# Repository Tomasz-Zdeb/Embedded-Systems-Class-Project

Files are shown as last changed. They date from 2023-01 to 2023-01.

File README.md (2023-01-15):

# Projekt zaliczeniowy

W ramach zaliczenia przedmiotu jesteśmy zobowiązani grupowo wykonać wspólny projekt, którego celem jest zaprojektowanie urządzenia elektronicznego opartego o mikroprocesor z rodziny **STM32**, służącego do rejestracji temperatury.

## Specyfikacja

* wykonanie projektu polega na zaprojektowaniu urządrzenia
* każdy komponent logiczny urządzenia powinien zostać dokładnie udokumentowany
* urządzenie powinno składać się z rzeczywistych komponentów elektronicznych dostępnych na rynku.
* wszelkie użyte komponenty elektroniczne powinny wnosić szacowaną wartość do kosztorysu
* projekt powinien zawierać schemat elektryczny całego urządzenia
* projekt ma formę dokumentu `.pdf`

## Cykl życia projektu

1. Ustalenie funkcjonalności, które urządzenie będzie realizować, na przykład:

* > pomiar temperatury za pomocą urządzenia pomiarowego np. **termorezystora**
* > przechowywanie szeregu czasowego wartości temperatur w pamięci trwałej
* > zapewnienie interfejsu do komunikacji z innymi urządzeniami, np. **Ethernet**
* > monitoring wartości temperatury w czasie rzeczywistym przy pomocy wyświetlacza alfanumerycznego **LCD**
  
2. Ustalenie jakie komponenty będą realizować zaplanowane funkcjonalności

* Należy mieć na uwadze ograniczenia interfejsów **I/O** mikrokontrolerów z rodziny **STM32** pod względem ilościowym i jakościowym . Do przeglądu dostępnych mikroprocesorów zaleca się użycie oprogramowania z [SDK](https://www.st.com/en/development-tools/stm32-software-development-tools.html#products) firmy **ST** używanego w ramach przedmiotu **Mikroprocesory i Mikrokontrolery**.

3. Opracowanie każdej z funkcjonalości w kontekście użytego komponentu

* opis charakterystyki komponentu i jego zastosowania w urządzeniu
* określelnie uproszczonego schematu podłączenia komponentu z danym interfejsem mikroprocesora
* uwzględnienie użytych komponentów w kosztorysie

4. Opracowanie całościowego schematu elektrycznego urządzenia

5. Opracowanie dokumentu stanowiącego podstawę do eksportu do `.pdf` / eksport bezpośredni `.md` => `.pdf`

* zawiera krótki opis urządzenia na wstępie
* (opcjonalnie) zawiera schemat logiczny urządzenia
* zawiera schemat elektryczny urządzenia
* zawiera opis każdej z funkcjonalności urządzenia w kontekście użytego komponentu
* zawiera kosztorys urządzenia
* zawiera uczestników projektu

6. Eksport dokumentu do `.pdf` i prezentacja prowadzącemu przedmiot: <mateusz.michalek@pk.edu.pl>

## Realizacja projektu

* Zaleca się korzystanie z edytora: [VS Code](https://code.visualstudio.com/)

  * sugestia dotycząca zalecanego rozszerzenia zawierającego pomoc w pisaniu dokumentów `.markdown` powinna pojawić się automatycznie. W przeciwnym wypadku ID: `DavidAnson.vscode-markdownlint`

* Treść projektu znajduje się w pliku [main](./main.md). Pracując nad projektem należy umieszczać tam owoce swojej pracy korzystając z formatowania języka [markdown](https://www.markdownguide.org/basic-syntax/).

* Obrazy znajdują się w katalogu `./images/`. Dodawanie obrazu do dokumentu polega na umieszczeniu obrazu w katalogu, a następnie stworzeniu odwołania w dokumencie [main](./main.md), np. `(alternatywny_tekst_dla_obrazu)[./images/]`

* Każdą jednostkową część pracy [commitujemy](https://git-scm.com/docs/git-commit) w lokalnym repozytorium na swojej maszynie na branchu dedykowanym danemu **issue**.

* W celu uaktualnienia centralnego repozytroium, należy wypushować brancha do centralnego repozytorium i otworzyć [pull request](https://docs.github.com/en/desktop/contributing-and-collaborating-using-github-desktop/working-with-your-remote-repository-on-github-or-github-enterprise/creating-an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) danego brancha z branchem **master**

* Za pomocą funkcjonalości serwisu **GitHub** - [Issues](https://github.com/features/issues):

  * przypisujemy dane zadanie do swojej osoby
  * tworzymy nowe zadania

## Status projektu

- [x] Inicjalizacja repozytorium
- [x] Stworzenie struktury projektu
- [x] Stworzenie zasad współtworzenia projektu
- [x] Dodanie wszystkich uczestników jako współtwórców repozytorium na **GitHub-ie**
- [x] **Issue**: Ustalenie funkcjonalności projektu
- [x] Utworzenie **issues** odpowiadających wszystkim funkcjonalnościom
- [x] Utworzenie **issues** odpowiadających pozostałym elementom realizacji projektu jak: **stworzenie schematu elektrycznego**
- [X] Realizacja rzeczonych issues
- [X] Uzupełnienie składu grupy
- [X] Publikacja projektu w formacie `.pdf`
- [X] Dostarczenie projektu do prowadzącego laboratorium (projekt zaliczony na ocenę: 5)

## Schemat elektryczny

Na podstawie researchu przeprowadzonego w [Issue: #4](https://github.com/Tomasz-Zdeb/Embedded-Systems-Class-Project/issues/4) schemat elektryczny urządzenia będzie tworzony przy pomocy oprogramowania: [KiCad](https://www.kicad.org/).

Schemat elektyczny znajduje się w katalogu: `/schematics/`

## Zadania których nie udało się zrealizować

- opis menu wraz z obsługą przy pomocy przycisków
- graficzny projekt gotowego urządzenia wraz z obudową
- opis modułu rozszerzeń
- przygotwanie kilku wariantów wyposażenia (wraz z cennikiem)

## Materiały

<p align="center">

zdjecie tablicu z sugestiami prowadzącego

</p>

## Opiekun repozytorium

### [Tomasz Zdeb](https://github.com/Tomasz-Zdeb)

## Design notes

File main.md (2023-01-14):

# Systemy Wbudowane - Projekt Grupy Laboratoryjnej 04

Realizacja projektu polega na zaprojektowaniu urządzenia embedded (systemu wbudowanego) do pomiaru temperatury. Projekt urządzenia w teorii mógłby stanowić podstawę do konstrukcji fizycznego prototypu urządzenia. Zakres projektu obejmuje dobór komponentów, mając na uwadzę:

- kompatybilność
- cenę
- rozmiary
- dostępność
- przystępność komponentu (tj. dostępność dokumentacji i schematów pozwalających na integrację komponentu)

W projekcie przedstawiono także schemat elektryczny potencjalnego urządzenia obrazujący połączenia komponentów przy zastosowaniu odpowiednich interfejsów.

## Skład grupy

- Imię Nazwisko (ta sekcja zostanie uzupełniona przed wysyłką projektu aby nie przechowywać danych uczestników w publicznym repozytorium)

## Specyfikacja urządzenia

Projektowane urządzenie stanowi kompaktowe i przystępne cenowo rozwiązanie do monitorowania temperatory przy pomocy termopary, z odczytem w czasie rzeczywistym lokalnie i zdalnie oraz zapisem na zewnętrznym nośniku. Urządzenie oparte jest o mikroprocesor: [STM32L151QDH6](https://www.mouser.pl/ProductDetail/STMicroelectronics/STM32L151QDH6?qs=pmcUWs1B1IIEPym5rr0MIA%3D%3D)

## Funkcjonalności

- Pomiar temperatury (przy pomocy termopary)
- Wyświetlanie warotści temperatury na alfanumerycznym wyświetlaczu **LCD** w czasie rzeczywistym
- Zapis pomiarów na karcie **micro SD**
- Możliwość odczytu aktualnej wartości i wartości zapisanych przez łączność **Bluetooth**
- Ustawienie alarmu, tj. wartości temperatury której przekroczenie (poniżej lub powyżej - w zależności od wybranego trybu) powoduje emisje sygnału dźwiękowego oraz powiadomienia w przypadku łączności **Bluetooth**

### Pomiar temperatury

W urządzeniu do pomiaru temperatury wykorzystywane są termopary typu K. Do interpretowania oraz przekształcania wyników pomiaru termopar wykorzystywane są dodatkowo konwertery **MAX31855KASA**.

#### Termopara

Poniżej przedstawiona jest częściowa charakterystyka wykorzystywanej termopary tpu K:

<p align="center">

| Zakres temperatur  | Precyzja pomiaru | Zakres napięcia wyjściowego |
| :---: | :---: | :---: |
| od -100°C do 500°C | ±2°C | od -6mV do +20mV |

</p>

#### Konwerter

Poniżej przedstawiona jest częściowa charakterystyka wykorzystywanego konwertera **MAX31855KASA**:

<p align="center">

| Zakres temperatury pracy | Rozdzielczość mierzonej temperatury |
| :---: | :---: |
| od -40°C do 125°C | 0.25°C |

</p>

Precyzja pomiaru a mierzona temperatura:

<p align="center">

| Mierzona temperatura | Temperatura pracy  | Precyzja pomiaru |
| :---: | :---: | :---: |
| od -200°C do +700°C  | od -20°C do +85°C  | ±2°C |
| od +700°C do +1350°C | od -20°C do +85°C  | ±4°C |
| od -270°C do +1372°C | od -40°C do +125°C | ±6°C |

</p>

#### Funkcjonalność

Pomiar temperatury odbywa się za pomocą termopar typu K. Typ K został wybrany z uwagi na dużą uniwersalność, niszki koszt i powszechność. Dodatkowo typ K oferuje odpowiednio szeroki zakres temperatury pomiaru. By ułatwić interpretacje wyników pomiaru termopary, wykorzystywane są konwertery **MAX31855KASA**, które przekształcają napięcie wyjściowe termopar na wartość temperatury w trywialnym do odczytania sygnale cyfrowym, niewymagającym dodatkowych przekształceń lub obliczeń. Sygnał cyfrowy z konwerterów jest następnie przesyłany przez SPI do mostka SC18IS606, z którego do mikrokontrolera przesyłany jest po I²C.

#### Schemat podłączenia konwertera i termopary

<p align="center">
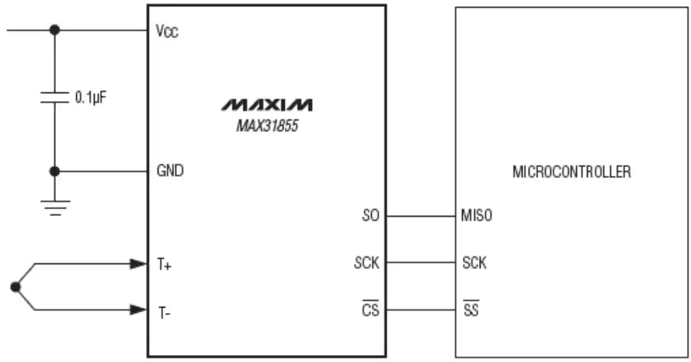
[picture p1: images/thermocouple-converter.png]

</p>

### Monitoring pomiaru w czasie rzeczywistym na alfanumerycznym ekranie LCD

#### Funkcjonalność

W urządzeniu do wyświetlania aktualnych wyników pomiarów wybraliśmy [LCD 2x16 wraz z konwerterem I²C LCM1602](https://botland.com.pl/wyswietlacze-alfanumeryczne-i-graficzne/2351-wyswietlacz-lcd-2x16-znakow-niebieski-konwerter-i2c-lcm1602-5904422309244.html). Możemy sterować zarówno wyświetlanym tekstem jak i podświetleniem, włączając lub wyłączając je w dowolnej chwili.  

#### Interfejs

Mikrokontroler, jako master w magistrali I2C, wysyła komendy i dane do konwertera I²C, który przetwarza je i przesyła do wyświetlacza LCD. To pozwala na komunikację między mikrokontrolerem, a wyświetlaczem za pomocą tylko dwóch linii SDA i SCL, zamiast wielu linii zwykłego interfejsu.

#### Schemat podłączenia konwertera i wyświetlacza

<p align="center">
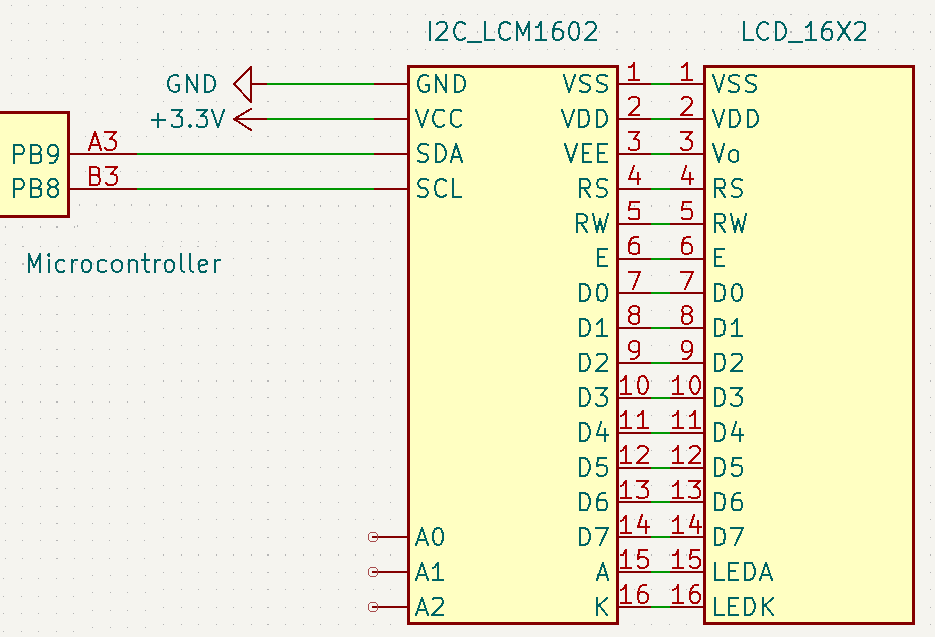
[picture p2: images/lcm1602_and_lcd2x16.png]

</p>

Warto też zauważyć, że w naszym konwerterze znajdują się niewykorzystane zworki do zmiany adresu. Z racji, iż mamy tylko jedno urządzenie nie musimy zmieniać owego adresu.

### Zapisywanie szeregu czasowego pomiarów na karcie Micro SD

Mikroprocesor **STM32L151QDH6** obsługuje funkcjonalność **SDIO** czyli natywną obsługę kart **SD** i **micro SD**.

#### Karta

Urządzenie korzysta z [karty SD](https://www.mouser.pl/ProductDetail/SanDisk/SDSDAF3-008G-I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) umieszczonej wewnątrz [gniazda](https://www.mouser.pl/ProductDetail/Amphenol-Commercial-Products/GSD090012SEU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). Karta z serii **Industrial** cechuje się dobrymi parametrami przesyłu jak i parametrami związanymi z wytrzymałością na warunki pracy (według [dokumentacji](https://www.mouser.pl/datasheet/2/669/SanDisk_02052018_SDSDAF3_SDSDQAF3-1285144.pdf)).

<p align="center">

| Wielkość pamięci | Maksymalna prędkość odczytu - zapisu | Zakres napięcia wejściowego |
| :---: | :---: | :---: |
| 8 GB | 80 MB/s - 50 MB/s | 2.7 V - 3.6 V |

</p>

#### Funkcjonalność

Urządzenie wykorzystuje czterobitowy tryb przesyłu (alternatywą był tryb jednobitowy), co wymagało zastosowania trzech dodatkowych linii danych, ale pozwala na osiągnięcie większej przepustowości komunikacji, co w związku z możliwością rozszerzenia urządzenia o dodatkowy moduł zwiększający maksymalną ilość podłączonych termopar jest uzasadnione.

Zgodnie z [artykułem](https://controllerstech.com/interface-sd-card-with-sdio-in-stm32/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) przy prawidłowym podłączeniu, obsługa zapisu i odczytu sprowadza się do odpowiedniej konfiguracji w trakcie pisania oprogramowania dla urządzenia.

Sposób zapisu danych na karcie polega na tworzeniu oddzielnego pliku dla każdej z termopar (nazewnictwo odpowiadające numerowi termopary) i umieszczania danych według ustalonego formatu, np.

```text
[YYYY-MM-DD-HH-mm-SS-miliseconds]<VALUE>
```

albo:

```text
[<miliseconds_since_epoch>]<VALUE>
```

urządzenie dysponowałoby kilkoma formatami zapisu, co możnaby zmieniać (np. poprzez zastosowanie zworek - mikroprocesor dysponuje dużą liczą niezagospodarowanych pinów, albo poprzez zaimplementowanie menu sterowanego przyciskami)

### Komunikacja przy pomocy interfejsu Bluetooth

#### Funkcjonalność

Komunikacja przy użyciu **Blueetooth** pozwala na odczyt danych w czasie rzeczywistym, oraz przegląd danych zapisanych na **karcie SD**. Takie rozwiązanie wymaga stworzenia dedykowanej aplikacji dla urządzenia.

#### Interfejs

Do komunikacji Bluetooth użyty został moduł **BMD-330** firmy [uBlox](https://www.u-blox.com/en/). Jest to komponent dostępny w sieci dostawcy [Mouser Electronics](https://www.mouser.pl/), cechujący się zadowalającym stosunkiem ceny do oferowanych parametrów.

Pozwala na komunikację w standardzie **Bluetooth 5.0** z uzyskaniem mocy wyjściowej na poziomie: **4 dBm** umożliwiając komunikację z prędkością do **2 Mb/s**. Urządzenie należy do klasy **Bluetooth Low Energy** pobierając nie więcej niż **12 mA** (dla napięcia zasilania z przedziału **1.7 V - 3.6 V**).

<p align="center">
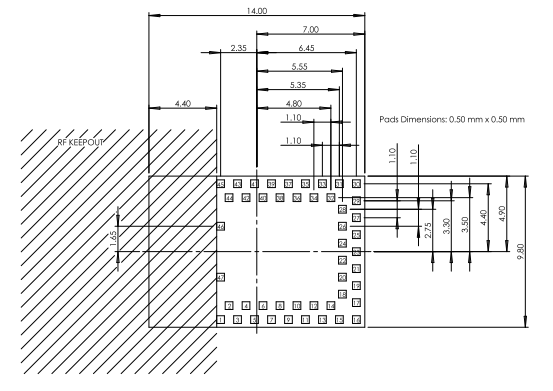
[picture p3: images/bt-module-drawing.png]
  
</p>

Moduł **BMD-330** jest stosunkowo złożonym urządzeniem zawierającym własny mikroprocesor, wbudowaną antenę i wiele komponentów pozwalających na wykorzystanie go na wiele sposobów. W naszym przypadku będziemy komunikować się z modułem przy użyciu magistrali **I2C**.

<p align="center">
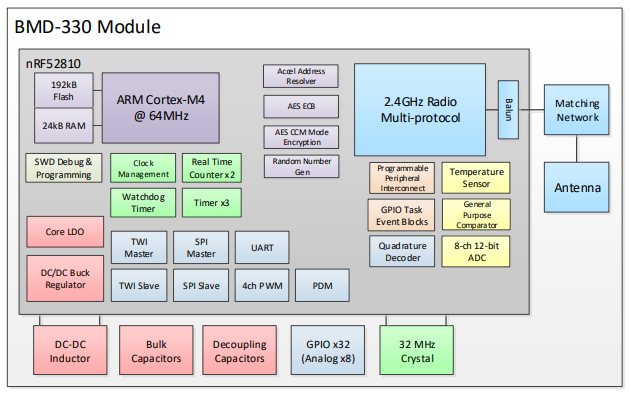
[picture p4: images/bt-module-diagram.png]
  
</p>

Zestawienie pinów modułu jest również bardzo obszerne, dlatego ze względu na przejrzystość schematu, stworzyliśmy własny model urządzenia zawierający jedynie używane przez nas linie, czyli zasilanie i linie interfejsu **I2C**.

### Emisja sygnałów dźwiękowych po przekroczeniu zadanej wartości progowej temperatury

#### Moduł buzzera

Do zrealizowania funkcjonalności użyto [modułu buzzera](https://botland.com.pl/buzzery-generatory-dzwieku/2963-modul-z-buzzerem-pasywnym-bez-generatora-czarny-5904422359263.html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) bez generatora od firmy **Iduino**.

Moduł zasilany jest napięciem **5V**, a pobór prądu nie przekracza **30mA**. Moduł generuje sygnał przy podaniu stanu wysokiego na pin **S**.

#### Funkcjonalność

Zgodnie z [instrukcją](https://arduinomodules.info/ky-006-passive-buzzer-module/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) urządzenie będzie pozwalało na generowanie sygnałów dźwiękowych o różnej wysokośći dzięki modulacji **PWM**.

Regulacji progu wyzwolenia alarmu oraz trybu działania tj. wyzwalanie przy zejściu poniżej zadanej temperatury albo po wyjściu ponad zadaną temperaturę jak i całkowitego wyłączenia alarmu dla danej termopary dokonujemy poprzez przyciski (tact switch'e) połączone z wejściami cyfrowymi mikroprocesora. Z racji na możliwość konfiguracji wbudowanych rezystorów pull-up albo pull-down na schemacie elektrycznym pominięto rezystory.

## Potencjalna konfiguracja

### **SDIO**

Wybrany mikroprocesor [STM32L151QDH6](https://www.mouser.pl/ProductDetail/STMicroelectronics/STM32L151QDH6?qs=pmcUWs1B1IIEPym5rr0MIA%3D%3D) obsługuje 4bitową obsługę **SDIO** (natywną komunikację z nośnikami w postaci kart SD i micro SD). Prawdopodobnie tryb 1-bitowy zapewniłby wystarczającą prędkość transmisji do zapisu danych pozyskiwanych przez urządzenie, przynajmniej dla wairantu z czteroma termoparami. Ze względu na możliwość dołączania kolejnych modułów rozszerzających liczbę termopar, bezpieczniej jest skorzystać z trybu w większej przepustowości.

<p align="center">
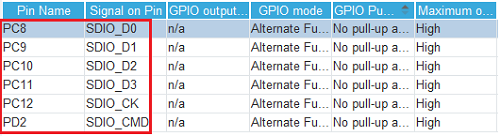
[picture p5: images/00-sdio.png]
  
</p>

### **I2C**

W przypadku konfiguracji interfejsu **I2C** można pozostawić domyślne ustawienia (tzn. nie zmniejszać prędkości zegara). Ze względu na możliwości rozszerzenia ilości używanych termopar wskazane jest zachowanie wysokiej przepustowości magistrali do przesyłu danych.

<p align="center">
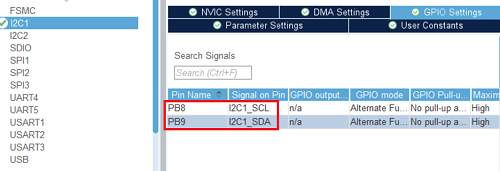
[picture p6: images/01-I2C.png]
  
</p>

<p align="center">
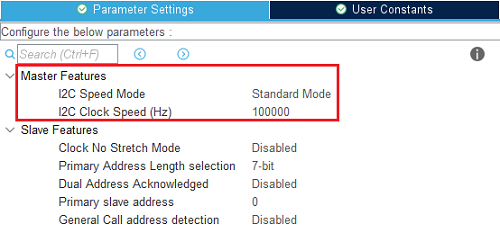
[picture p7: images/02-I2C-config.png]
  
</p>

Z analizy dokumentacji [konwertera napięć termopary](https://github.com/Tomasz-Zdeb/Embedded-Systems-Class-Project/issues/8) (tj. modułu interpretującego napięcie w kontekście temperatury):

- <https://www.mouser.pl/new/maxim-integrated/maximmax31855/>
- <https://www.mouser.pl/pdfDocs/MAX31855.pdf>

oraz analizie materiałów dotyczących interfejsu **SPI**:

- <https://www.youtube.com/watch?v=eFKeNPJq50g&ab_channel=Digi-Key>
- <https://fastbitlab.com/nss-setting-stm32-master-slave-mode/>
- <https://www.digikey.com/en/maker/projects/getting-started-with-stm32-how-to-use-spi/09eab3dfe74c4d0391aaaa99b0a8ee17>

<p align="center">
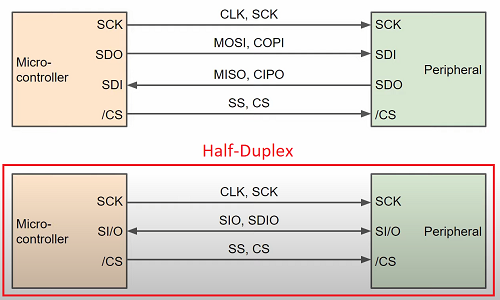
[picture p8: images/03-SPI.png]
  
</p>

stwierdzono, że w celu zapewnienia właściwej komunikacji z komponentem używającym tej magistrali konfiguracja interfejsu **SPI** polegała będzie na ustawieniu trybu:

- **Master** (Mikroprocesor-master, konwerter-slave)
- **Half-Duplex**

Ze względu na brak jednolitego standardu komunikacji **SPI** istotne są parametry **CPOL** i **CPHA** określające przebieg transmisji względem polaryzaji zegara i linii danych.

<p align="center">
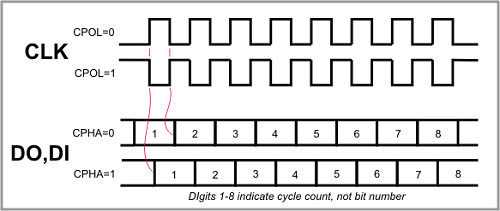
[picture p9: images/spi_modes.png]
  
</p>

Według dokumentacji konwertera należy przyjąć wartości:

- **CPOL** = 0
- **CPHA** = 0

Ze względu na prostotę użytkowania interfejsu **I2C** i potrzębę podłączenia większej ilości urządzeń wykorzystujących interfejs **SPI** (pomiar przy pomocy więcej niż jednej termopary) w projekcie korzystamy z [mostka I2C do SPI](https://www.mouser.pl/ProductDetail/NXP-Semiconductors/SC18IS606PWJ?qs=pBJMDPsKWf02qtdqbj2bbA%3D%3D), który pozwala na podłączenie do trzech linii (urządzeń) **SPI** (wg. [dokumentacji](https://www.mouser.pl/datasheet/2/302/SC18IS606-2933187.pdf)).

### **PWM**

Najistotniejszym elementem konfiguracji wyjścia PWM jest ustawienie źródła sygnału zegara na zegar wewnętrzny i ustawienie generowania sygnału PWM na kanale pierwszym. Pozostałe parametry można pozostawić z wartościami domyślnymi.

<p align="center">
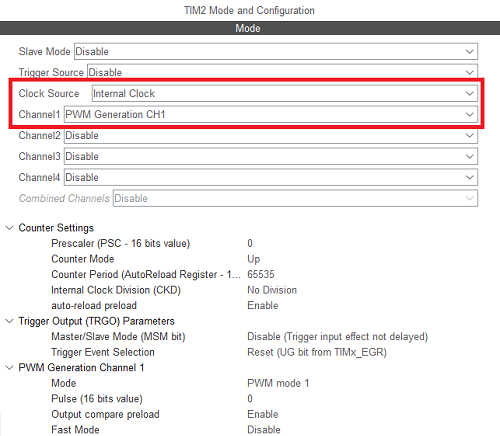
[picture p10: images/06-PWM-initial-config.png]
  
</p>

W kofniguracji wykorzystywany jest wewnętrzny zegar mirkoprocesora (Zastosowanie zewnętrznego zegara byłoby w tym przypadku niczym nieuzasadnione)

<p align="center">
  
</p>

### **GPIO**

W przypadku wejść cyfrowych, konfiguracja polega na arbitralnym wyborze niezagospodarowanych pinów (których wybrany procesor posiada sporo) i ustawienia ich trybu pracy na input mode.

<p align="center">
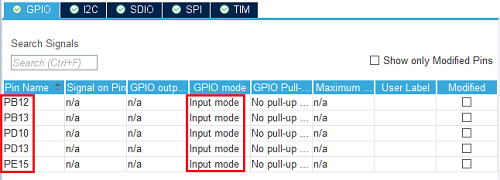
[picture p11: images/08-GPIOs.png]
  
</p>

### Zestawienie pinów

- **SDIO**

<p align=center>

| Sygnał | Pin  |
| :----: | :--: |
| D0 | PC8  |
| D1 | PC9  |
| D2 | PC10 |
| D3 | PC11 |
| CK | PC12 |
|  CMD | PD2  |

</p>

- **I2C**

<p align=center>

| Sygnał | Pin |
| :----: | :-: |
|  SCL | PB8 |
|  SDA | PB9 |

</p>

- **PWM**

<p align=center>

| Sygnał | Pin |
| :----: | :-: |
|  CH1 | PA5 |

</p>

- **GPIO**

<p align = center>

| Pin  |
| :--: |
| PB12 |
| PB13 |
| PD10 |
| PD13 |
| PE15 |

</p>

## Schemat elektryczny

<p align="center">
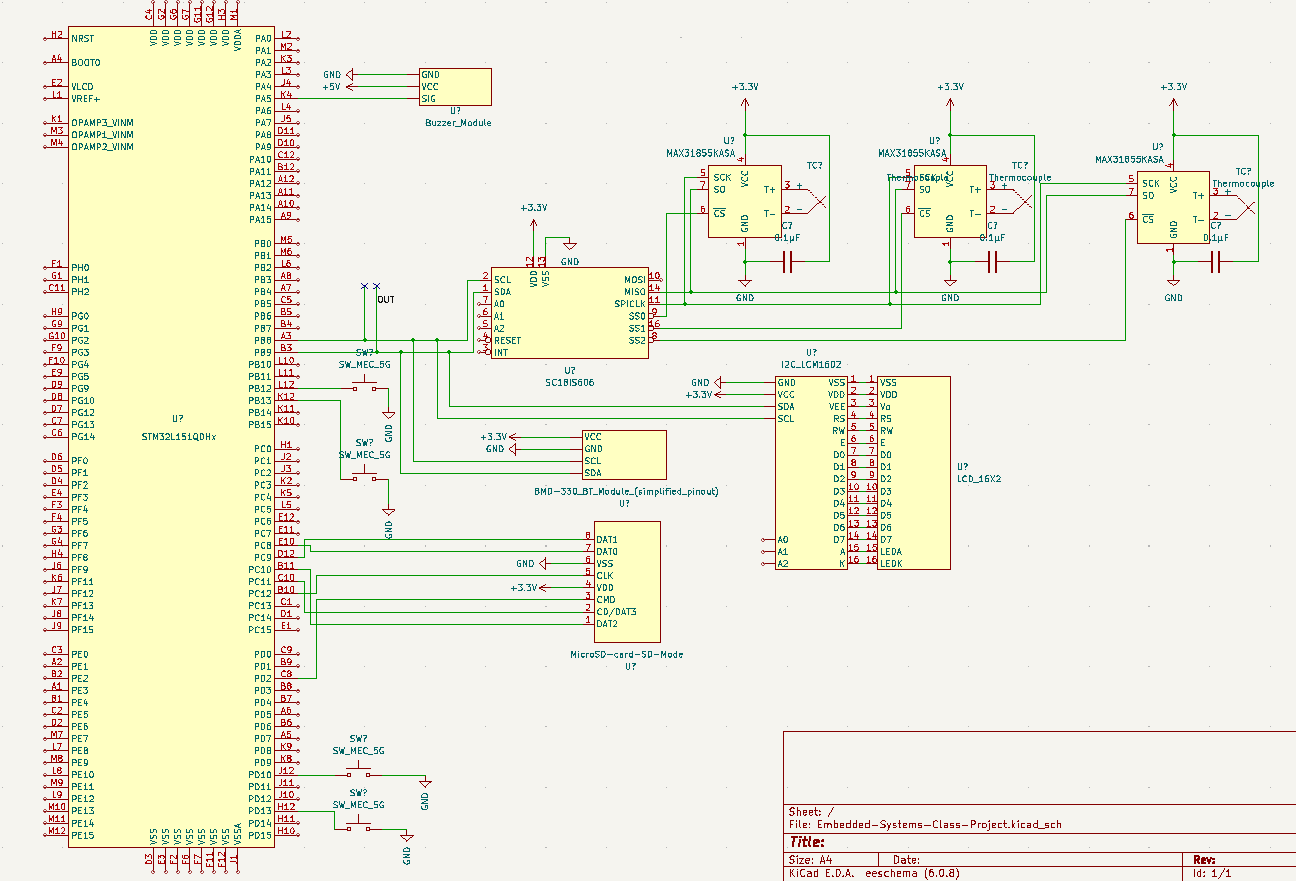
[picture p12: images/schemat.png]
  
</p>

## Kosztorys

### Ceny jednostkowe komponentów

- moduł Bluetooth: 27,80 zł
- mikroprocesor: 39,20 zł
- buzzer: 5,90 zł
- Tact Switch (niebieski): 3,40 zł
- Tact Switch (czerwony): 3,40 zł
- Tact Switch (czarny): 2,90 zł
- gniazdo karty pamięci SD z wyrzutnikiem: 2,60 zł
- karta pamieci: 293,70 zł
- wyświetlacz LCD + konwerter: 24,70 zł
- termopara typu K: 21,47 zł
- chip do interpretowania napięć x3: 49,98 zł (149,94 zł)
- obudowa: 10 zł
- interfejs wyspecjalizowany Semiconductor SC18IS606PWJ: 17,94 zł

### Sumaryczna cena komponentów urządzenia

652,93 zł

### Potencjalna cena rynkowa urządzenia

914,10 zł - przyjąłem 140% ceny komponentów aby pokryć koszty produkcji i zapewnić marżę dla wytwórcy
(cena jest podana przy zakupie jednego urządzenia, w przypadku zamówień hurtowych cena może być nisza nawet o 30%)

## Pliki źródłowe projektu

pliki źródłowe projektu wraz z odniesieniami do źródeł (znajdujących się w GitHub Issues - używanych do definiowania zadań) są dostępne w [publicznym repozytorium](https://github.com/Tomasz-Zdeb/Embedded-Systems-Class-Project)

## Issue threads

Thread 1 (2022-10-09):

Ustalenie funkcjonalności projektu

Tomasz-Zdeb, 2022-10-09:
Abyśmy mogli przejść do dalszego etapu realizacji projektu, w którym każdy będzie pracował nad wybranym przez siebie elementem systemu musimy ustalić jakie funkcjonalności będzie posiadał nasz **Rejestrator temperatury**.

Musimy mieć na uwadze ograniczoną liczbę wejść i wyjść w mikroprocesorach z rodziny **STM32**, w związku z czym nie przesadzajmy z ilością funkcjonalności takiego urządzenia. Proponuję aby zawrzeć umiarkowaną ilość funkcjonalności i po prostu zrobić porządnie projekt od początku do końca.

W mojej opinii, must have to:

* pomiar temperatury np. przy pomocy termopary
* monitoring wartości temperatury w czasie rzeczywistym przy pomocy wyświetlacza alfanumerycznego LCD
* przechowywanie szeregu czasowego wartości temperatur w pamięci trwałej
* zapewnienie interfejsu do komunikacji z innymi urządzeniami, np. Ethernet

---

### Proszę o zgłaszanie propozycji funkcjonalności w tym **issue**

---

Na podstawie poczynionych ustaleń utworzę kolejno **issues** dotyczące każdej funkcjonalności/zadania do wykonania umożliwiając każdemu członkowi zespołu przypisanie sobie danego **issue** i pracę nad konkretnym elementem projektu.

jackpie2, 2022-10-11:
Co do interfejsu komunikacji z innymi urządzeniami, to potencjalną alternatywą dla Ethernetu może być też jakiś moduł WIFI/Bluetooth, jeśli celujemy w coś bardziej typu urządzenia IoT, bo to z reguły tam jest standardem. Oczywiście o ile nie skomplikuje to znacząco projektu

Tomasz-Zdeb, 2022-10-26:
Warto byłoby dodać LED sygnalizujący obecność zasilania - np. w kolorze czerwonym.

Tomasz-Zdeb, 2022-10-26:
Musimy zdecydować, który interfejs zaimplementujemy w urządzeniu. Proszę o wypowiedzi w kontekście interfejsu, kto jest za skorzystaniem z jakiego interfejsu (uzasadnienia mile widziane 😀):
* **Bluetooth**
* **Wi/Fi**
* **Ethernet**

michalwarchol, 2022-11-11:
Według mnie fajnie byłoby żeby to działało przez bluetooth, a telefonie apka pokazująca temperaturę zczytaną z urządzenie przez ten interfejs :D

BlessedSamhain, 2022-11-11:
Generalnie opcja Bluetooth mi się podoba.

Tomasz-Zdeb, 2022-11-13:
@PWWP @michalwarchol @bdttd000 @jackpie2 @D4RK0N3dev @BlessedSamhain @S1mon1

Proszę o oddanie głosu w temacie interfejsu który wybieramy do komunikacji ⬆⬆⬆

Tomasz-Zdeb, 2022-11-13:
@PWWP @michalwarchol @bdttd000 @jackpie2 @D4RK0N3dev @BlessedSamhain @S1mon1

Proszę o przedstawienie ewentualnych nowych funkcjonalności, albo wyrażenie opinii, że to co mamy jest już ok.

---

Z mojej strony to co już mamy wydaje się okej, nie ma co przeprowadzać jakiegoś overengineeringu dla prostego urządzenia

D4RK0N3dev, 2022-11-13:
> @PWWP @michalwarchol @bdttd000 @jackpie2 @D4RK0N3dev @BlessedSamhain @S1mon1
>
> Proszę o oddanie głosu w temacie interfejsu który wybieramy do komunikacji ⬆⬆⬆

Jestem za bluetoothem 😉

jackpie2, 2022-11-14:
Jestem za bluetooth i zgadzam się z tym, że mamy już wystarczająco.

Closed 2022-12-28.

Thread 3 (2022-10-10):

Ograniczenie zasad akceptacji pull requestów

Tomasz-Zdeb, 2022-10-10:
Chciałbym abyśmy znaleźli sposób na ograniczenie możliwości akceptacji pull requestów, aby administrator mógł pilnować, czy ktoś nie próbuje przemycić na maina fuszerki 😀

Tomasz-Zdeb, 2022-10-11:
Zrealizowałem powyższe instrukcje na masterze. Poproszę @BlessedSamhain o sprawdzenie, ponieważ stanowi osobę trzecią z punktu widzenia tego PR.
___

Poniższy komunikat pozwala mieć nadzieję na poprawne funkcjonowanie tego rozwiązania 😊
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

Tomasz-Zdeb, 2022-10-11:
Przy pomocy @BlessedSamhain sprawdziłem obecne zachowanie mechanizmu. Wszystko działa zgodnie z planem. Dobra robota! @jackpie2 😀

Closed 2022-10-11.

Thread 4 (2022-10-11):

Research na temat software do projektowania schematów elektrycznych

jackpie2, 2022-10-11:
W projekcie potrzebny będzie schemat elektryczny urządzenia, a do jego wykonania przydałby się jakiś program. W związku z tym należy zrobić rozeznanie jakie oprogramowanie byłoby do tego najlepsze.

Tomasz-Zdeb, 2022-10-11:
Priorytetem w poszukiwaniu softu do tego zadania powinna być prostota. Fajnie gdyby zawierał **out of the box** jakąś bazę komponentów w której znalazły by się mikrokontrolery z rodziny **STM32** aby można było zaimportować taki element.

jackpie2, 2022-10-11:
Całkiem obiecująco wygląda [KiCad](https://www.kicad.org/), ma spory wybór komponentów z rodziny STM32, aktywną społeczność i też nie ma problemu z importowaniem do niego dodatkowych schematów.

Tomasz-Zdeb, 2022-10-11:
Dobra robota 👍 Zatem ustalamy **KiCad** jako rekomendowany sofcik do stworzenia schematu elektrycznego

Closed 2022-10-11.

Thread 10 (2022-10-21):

Research i wybór komponentu do przechowywania danych

jackpie2, 2022-10-21:
Zresearchowanie i wybranie komponentu, odpowiedzialnego za przechowywanie danych (zarejestrowanych temperatur), z kategorii must have, wspomnianej w #1.

Tomasz-Zdeb, 2022-10-26:
Sugeruję skorzystanie z [niniejszego komponentu](https://botland.com.pl/akcesoria-do-kart-pamieci/1507-modul-czytnika-kart-sd-5903351241342.html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)

Tomasz-Zdeb, 2022-11-13:
W trakcie laboratoriów, dowiedziałem się, że prawdopodobnie dostęp do karty SD można przeprowadzić w STM32 bezpośrednio bez użycia dodatkowych komponentów.

## Materiały

Zamieszczam materiały, które mogą zawierać potencjalne wskazówki jak dokonać odpowiedniej konfiguracji.

<https://01001000.xyz/2020-08-09-Tutorial-STM32CubeIDE-SD-card/>
<https://www.youtube.com/watch?v=fRfRwMyNE7A&ab_channel=self-studyelectronicengineer>

BlessedSamhain, 2022-11-27:
Proponuję zastosowanie karty pamięci https://botland.com.pl/karty-pamieci-microsd-sd/2123-karta-pamieci-goodram-m1aa-microsd-16gb-100mbs-uhs-i-klasa-10-z-adapterem-5908267930137.html wraz z gniazdem https://botland.com.pl/akcesoria-do-kart-pamieci/1113-gniazdo-do-karty-pamieci-sd-z-wyrzutnikiem-sd238-5904422349318.html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 . To powinno wspierać SDIO, o którym pisał wcześniej Tomek

Tomasz-Zdeb, 2022-11-27:
Ok, ciekawy wybór. Dobra robota 👍

BlessedSamhain, 2022-12-30:
Link do wyżej wskazanej karty wygasł, w związku z czym przedstawiam nową propozycję karty **micro SD** o pojemności 64 GB, obsługującej też tryb **SPI** (co prawdopodobnie nie będzie używane ze względu na wbudowaną w mikroprocesor funkcjonalność **SDIO**), dostępną na stanie magazynowym dostawcy **Mouser Electronics**:

https://www.mouser.pl/ProductDetail/Swissbit/SFSD016GN1AM1MT-I-5E-21P-STD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

BlessedSamhain, 2022-12-31:
Ponieważ tamta karta jest dość droga, to można by w zamian wziąć tę:

https://www.mouser.pl/ProductDetail/SanDisk/SDSDAF3-008G-I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

Closed 2022-12-31.

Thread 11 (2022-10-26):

Stworzenie sekcji dotyczącej pomiaru temperatury w main.md

Tomasz-Zdeb, 2022-10-26:
Komponenty do pomiaru temperatury zostały wybrane: #8. Teraz należy dokonać formalizacji treści projektu, tj. między innymi:
- [x] Stworzenie sekcji dotyczącej funkcjonalności realizowanej przez komponenty w pliku: [main.md](https://github.com/Tomasz-Zdeb/Embedded-Systems-Class-Project/blob/master/main.md). Treść powinna zawierać:
   - [x] Przedstawienie charakterystyki komponentów realizujących zadaną funkcjonalność
   - [x] Opis funkcjonalności
   - [x] Schemat logiczny obrazujący podłączenie komponentów (ten z dokumentacji układu [MAX31855](https://www.mouser.pl/new/maxim-integrated/maximmax31855/) prezentuje się bardzo przejrzyście)
- [x] Dodanie komponentów do schematu elektrycznego projektu (katalog: [schematics](https://github.com/Tomasz-Zdeb/Embedded-Systems-Class-Project/tree/master/schematics))
  - [x] W przypadku braku odpowiedniego modelu stworzenie go
  - [x] Połączenie modelu z układem (mikroprocesor i zasilanie)

Tomasz-Zdeb, 2022-12-30:
## FYI
- w Issue: #28 zostały określone piny, używane przez konkretne interfejsy
- w Issue #25 dodano model mikroprocesora do schematu elektrycznego

W związku z czym można dodać komponenty do schematu elektrycznego wraz ze stworzeniem odpowiednich połączeń (co jest do zrobienia w ramach niniejszego zadania)

Tomasz-Zdeb, 2023-01-03:
## Hotfix

Zapomniałem o ważnej funkcjonalności, tj. obsłudze więcej niż jednej termopary.
- Przyjmijmy cztery termopary połączone w [daisy chain](https://www.analog.com/en/technical-articles/daisychaining-spi-devices.html) (co będzie wymagało czterech konwerterów)
- wyjście do obsługi modułu rozszerzeń (tj. po prostu trzy zaciski aby kontynuować podłączenie we wspomnianej konfiguracji.

Zaktualizuję zadanie dotyczące kosztorysu https://github.com/Tomasz-Zdeb/Embedded-Systems-Class-Project/issues/33

Tomasz-Zdeb, 2023-01-05:
Zrealizowane w **PR**: #35

Closed 2023-01-05.

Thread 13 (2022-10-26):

Research i wybór komponentu do generowania sygnałów dźwiękowych po osiągnięciu zadanej temperatury

michalwarchol, 2022-10-26:
Na przykład sygnały ostrzegawcze gdy temperatura spadnie poniżej zera, lub gdy wzrośnie powyżej 30 stopni.

michalwarchol, 2022-11-11:
Proponuję skorzystanie z tego [głośniczka](https://eu.mouser.com/ProductDetail/CUI-Devices/CDS-4028-16?qs=Rp5uXu7WBW9mlyNssDdIqQ%3D%3D)

michalwarchol, 2022-11-11:
Tutaj jest instrukcja jak coś takiego podpinać: https://os.mbed.com/users/4180_1/notebook/using-a-speaker-for-audio-output/

michalwarchol, 2022-11-11:
Tutaj [model 3D](https://www.cuidevices.com/product/resource/3dmodel/cds-4028-16) tego głośnika

michalwarchol, 2022-11-11:
> Przydatny może być też [ten poradnik](https://www.instructables.com/LETS-MAKE-a-PORTABLE-SPEAKER-ON-a-BREADBOARD/)

W tym poradniku jest też wykaz innych komponentów które są potrzebne do podłączania tego ustrojstwa. Jakieś kondensatory, potencjometr itp.

michalwarchol, 2022-11-11:
Może sie jeszcze przydać taki [poradnik](https://youtu.be/qNLvoSQCx60)

Tomasz-Zdeb, 2022-11-11:
> Proponuję skorzystanie z tego [głośniczka](https://eu.mouser.com/ProductDetail/CUI-Devices/CDS-4028-16?qs=Rp5uXu7WBW9mlyNssDdIqQ%3D%3D)

Mam problem z otwarciem zamieszczonego linku. Strona główna Mausera działa bez zarzutów, zatem musi to być problem z linkiem.

---

## Organizacja

### Nazwa i zakres Issue

Zalecam zmianę nazwy niniejszego **Issue** zgodnie z konwencją, na np.: "**Research i wybór komponentów do emisji sygnałów dźwiękowych po osiągnięciu konkretnych temperatur**" i oczywiście ograniczenie zakresu niniejszego **Issue** tylko do wyboru komponentów.

### Relizacja w odrębnym wątku (Issue)

Do samej realizacji zadania - tj. dodania komponentu do schematu i stworzenie treści, która będzie zawierać się w ostatecznym dokumencie stanowiącym nasz projekt, utwórzmy oddzielne **Issue** po zamknięciu tego, aby zachować jak największą granulację zadań, a co za tym idzie możliwość podziału obowiązków 😀

## Komentarz

Zasadniczo skorzystanie z takiego kolosa w naszym drobnym urządzeniu embedded, jest zdecydowanie overkillem, między innymi ze względu na rozmiary, konsumpcje energii elektrycznej, złożoność aplikacji a nawet cenę. 😯

## Komponenet

Tak na prawdę nie potrzebujemy emitować dźwięku złożonego z wielu tonów - **buzzer** wydaje się być idealnym rozwiązaniem. Zasadniczo nie zależy nam też szczególnie na modulacji tonu - więc dla uproszczenia możemy skorzystać z buzzera z generatorem 😎 co pozwoli na sterowanie po prostu za pomocą podawania sygnału wysokiego gdy chcemy emitować dźwięk i sygnału niskiego gdy nie chcemy emitować dźwięku. Oczywiście ton będzie z góry ustalony i nie będzie można go zmieniać, ale w takim urządzeniu zmiana tonu sygnału nie jest najważniejsza (tym bardziej w czasach kryzysu gospodarczego i braków na rynku półprzewodników 😪)

Polecam: [komponent tego typu :)](https://botland.com.pl/buzzery-generatory-dzwieku/786-buzzer-z-generatorem-5v-12mm-tht-5904422366940.html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). Wpasowuje się on w kontekst naszego urządzenia embedded zarówno pod względem rozmiaru, poboru energii, poziomu trudności aplikacji i ceny.

## Ustawianie thresholdu

Potencjometry stanowią efektywny sposób kontrolowania progu aktywacji. Ale z racji zastosowania interfejsu do komunikacji urządzenia z innymi urządzeniami, ciekawie byłoby móc modyfikować parametry naszego urządzenia również zdalnie.

Jeżeli próg będziemy modyfikować za pomocą potencjometrów, uniemożliwimy (albo skomplikujemy do stopnia pozbawiającego sens skorzystania z takiego rozwiązania) możliwość ustawiania parametrów zdalnie.

Proponuję skorzystać po prostu z **tact switchy** (które btw. również w pasowują się w kontekst naszego niewielkiego urządzenia embedded). Możemy skorzystać ze skojarzeń i zastosować color coding: [niebieski](https://botland.com.pl/tact-switch/11131-tact-switch-12x12mm-z-nasadka-kwadrat-niebieski-5szt-5904422307554.html) dla zmniejszania progu i [czerwony](https://botland.com.pl/tact-switch/11134-tact-switch-12x12mm-z-nasadka-kwadrat-czerwony-5szt-5904422307547.html) dla zwiększania progu.

Zmiana parametrów za pomocą impulsów (generowanych przez zwarcie przycisku) nie ogranicza nas w kontrolowaniu wartości parametru również zdalnie i przesuwa złożoność realizacji takiego rozwiązania w warstwę programistyczną a nie sprzętową. (czyli poza zakres naszego zadania)

## Konkluzja

Zastosowanie zaproponowanych przeze mnie rozwiązań uprości konstrukcje urządzenia i co również bardzo istotne dla nas jako realizatorów zadania uprości jego realizację 😉

Tomasz-Zdeb, 2022-12-28:
W nawiązaniu do naszej rozmowy, uważam że zastosowanie zaproponowanego przez @michalwarchol [rozwiązania](https://arduinomodules.info/ky-006-passive-buzzer-module/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) odpowiada potrzebom naszego urządzenia. Proponuję zastosowanie [tego modułu](https://botland.com.pl/buzzery-generatory-dzwieku/2963-modul-z-buzzerem-pasywnym-bez-generatora-czarny-5904422359263.html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)

Closed 2022-12-28.

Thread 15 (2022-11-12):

Stworzenie sekcji dotyczącej wyświetlacza LCD w main.md

jackpie2, 2022-11-12:
Element w postaci wyświetlacza LCD z konwerterem I2C został wybrany (#9). Następne kroki:

- [x] Stworzenie sekcji dotyczącej funkcjonalności realizowanej przez komponenty w pliku: [main.md](https://github.com/Tomasz-Zdeb/Embedded-Systems-Class-Project/blob/master/main.md). Treść powinna zawierać:
  - [x] Przedstawienie charakterystyki komponentów (wyświetlacz LCD i konwerter I2C) realizujących zadaną funkcjonalność
  - [x] Opis funkcjonalności
  - [x] Schemat logiczny obrazujący podłączenie komponentów (opcjonalnie)
- [x] Dodanie komponentów do schematu elektrycznego projektu. (katalog: [schematics](https://github.com/Tomasz-Zdeb/Embedded-Systems-Class-Project/tree/master/schematics))
  - [x] W przypadku braku odpowiedniego modelu stworzenie go
  - [x]  Połączenie modelu z układem (mikroprocesor i zasilanie)

jackpie2, 2022-11-17:
Co do dodawania komponentów do schematu, to proponowałbym dodanie całej płytki konwertera, a nie samego układu PCF8574. PCF8574 jest dostępny w KiCadzie, ale podłączenie nie jest trywialne i z tego co rozumiem wymaga dodawania odpowiednich rezystorów i innych pośrednich elementów.

Niestety nie znalazłem żadnej dokumentacji całego układu, na [stronie](https://botland.com.pl/wyswietlacze-alfanumeryczne-i-graficzne/2351-wyswietlacz-lcd-2x16-znakow-niebieski-konwerter-i2c-lcm1602-5904422309244.html) też nie ma linka do niej, a z mojego krótkiego researchu wynika też, że nazwa LCM1602 może dotyczyć samego wyświetlacza, choć i tutaj znalazłem sprzeczne informacje. W każdym razie [tutaj](https://www.mikrocontroller.net/attachment/521754/PCF8574_I2C_LCD_Cir_En.pdf) i [tutaj](https://www.electronicshub.org/pcf8574-i2c-lcd-with-arduino/) są jakieś sensowne opisy tych płytek i najlepiej byłoby na bazie tego stworzyć nowy, prosty komponent w KiCadzie, skupiając się głównie na wyjściach/wejściach, a następnie podpiąć go bezpośrednio do wyświetlacza LCD.

Tomasz-Zdeb, 2022-11-27:
W związku z ostatnim [Pull Requestem](https://github.com/Tomasz-Zdeb/Embedded-Systems-Class-Project/pull/16) można odznaczyć podzadanie odpowiadające zaktualizowaniu schematu elektrycznego jako zrealizowane. Dobra robota! 👍

Teraz pozostały do zrobienia kolejne punkty, dotyczące opisu komponentu i funkcjonalności

Tomasz-Zdeb, 2022-12-30:
## FYI
- w Issue: #28 zostały określone piny, używane przez konkretne interfejsy
- w Issue #25 dodano model mikroprocesora do schematu elektrycznego

W związku z czym można dodać komponenty do schematu elektrycznego wraz ze stworzeniem odpowiednich połączeń (co jest do zrobienia w ramach niniejszego zadania)

Closed 2023-01-14.

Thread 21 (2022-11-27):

Stworzenie sekcji dotyczącej przechowywania danych w main.md

Tomasz-Zdeb, 2022-11-27:
Dokonano wyboru komponentów: (#10). Kolejne etapy realizacji projektu w kontekście niniejszej funkcjonalnośc to:
- [x] Stworzenie sekcji dotyczącej funkcjonalności realizowanej przez komponenty w pliku: [main.md](https://github.com/Tomasz-Zdeb/Embedded-Systems-Class-Project/blob/master/main.md). Treść powinna zawierać:
  - [x] Przedstawienie charakterystyki komponentów realizujących zadaną funkcjonalność
  - [x]  Opis funkcjonalności
  - [x] Schemat logiczny obrazujący podłączenie komponentów (Opcjonalnie)
- [x] Dodanie komponentów do schematu elektrycznego projektu (katalog: [schematics](https://github.com/Tomasz-Zdeb/Embedded-Systems-Class-Project/tree/master/schematics))
  - [x]  W przypadku braku odpowiedniego modelu stworzenie go
  - [x] Połączenie modelu z układem (mikroprocesor i zasilanie)

Tomasz-Zdeb, 2022-12-30:
## FYI
- w Issue: #28 zostały określone piny, używane przez konkretne interfejsy
- w Issue #25 dodano model mikroprocesora do schematu elektrycznego

W związku z czym można dodać komponenty do schematu elektrycznego wraz ze stworzeniem odpowiednich połączeń (co jest do zrobienia w ramach niniejszego zadania)

BlessedSamhain, 2023-01-13:
https://controllerstech.com/interface-sd-card-with-sdio-in-stm32/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

Closed 2023-01-14.

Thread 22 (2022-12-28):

Research i wstępny wybór mikroprocesora

Tomasz-Zdeb, 2022-12-28:
Aby móc tworzyć połączenia na schemacie elektrycznym niezbędne jest umieszczenie na nim mikroprocesora, dlatego model mikroprocesora musi zostać wybrany. Jeżeli po dodaniu wszystkich funkcjonalności będzie można zaobserwować redundancje możliwości (chodzi głównie o dostępne interfejsy) mikroprocesora, wówczas należy będzie skorygować wybór na model o mniejszej ilości interfejsów. Jeżeli nie wystąpi redundancja, wskazane będzie pozostanie przy wybranym mikroprocesorze
AC:
- [ ] dokonano wyboru mikroprocesora z modeli dostępnych w oprogramowaniu [STM32 IDE](https://www.st.com/en/development-tools/stm32cubeide.html)
- [ ] mikroprocesor obsługuje wszystkie (pod względem ilościowym i jakościowym) interfejsy używane przez komponenty urządzenia

Tomasz-Zdeb, 2022-12-28:
### Wymagania
- **termopara**: SPI
- **wyświetlacz**: I2C, 2x wejście cyfrowe (BRIGHTNESS,CONTRAST)
- **pamięć**: SDIO
- **interfejs zewnętrzny** (Bluetooth) I2C/SPI - wybieram I2C
- **sygnały dźwiękowe** 3x wejście cyfrowe dla przycisku (UP,DOWN,TONE), wyjście PWM zdolne zapewnić prąd 30mA

BlessedSamhain, 2022-12-28:
Proponuję zastosowanie mikroprocesora [STM32L151QDH6](https://www.mouser.pl/ProductDetail/STMicroelectronics/STM32L151QDH6?qs=pmcUWs1B1IIEPym5rr0MIA%3D%3D).
Obsługuje on wskazane powyżej interfejsy. Wyjątkowe wyzwanie stanowiło znalezienie mikroprocesora z rodziny STM32, który obsługuje **SDIO**, dostępnego na stanie magazynowym w sieci sklepów **Mouser Electronics**. Udało się to częściowo. Mikroprocesor jest dostępny na zamówienie, ale biorąc pod uwagę scenariusz powstawania naszego urządzenia powinno być to dopuszczalne.

Mikroprocesory z serii **STM32L151QDHx** są dostępne zarówno w programie **STM32CubeIDE**, jak i **KiCad**, w związku z czym będziemy mogli bezproblemowo zorientować się w potencjalnej konfiguracji (tzn. jaki interfejs możemy skonfigurować na jakim pinie), a następnie dodać go do schematu elektrycznego i dokonać odpowiednich połączeń (na podstawie wiedzy z etapu konfiguracji).

Tomasz-Zdeb, 2022-12-28:
Super, zatem wybieramy rzeczony mikroprocesor. 👍

Closed 2022-12-28.

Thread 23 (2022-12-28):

Research i wybór komponentu do komunikacji bluetooth

Tomasz-Zdeb, 2022-12-28:
AC:
- [ ] dokonano wyboru komponentu umożliwiającego komunikację **Blueetoth**
- [ ] wybrany komponent wykorzystuje interfejs obsługiwany przez mikroprocesory z rodziny **STM32** do komunikacji z mikroprocesorem

Tomasz-Zdeb, 2022-12-28:
Proponuję zastosowanie [modułu](https://www.mouser.pl/ProductDetail/u-blox/BMD-330-A-R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). Cechuje się on:
- pożądanymi przez nas interfejsami (SPI, I2C)
- przyzwoitą ceną (~27,80 zł w porównaniu z wieloma dostępnymi na stanie modułami, których cena to >40zł)
- dostępnością magazynową

Closed 2022-12-28.

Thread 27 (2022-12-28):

Stworzenie sekcji dotyczącej emisji sygnałów dźwiękowych po przekroczeniu progu w main.md

Tomasz-Zdeb, 2022-12-28:
Dokonano wyboru komponentów: #13  Kolejne etapy realizacji projektu w kontekście niniejszej funkcjonalnośc to:
- [x] Stworzenie sekcji dotyczącej funkcjonalności realizowanej przez komponenty w pliku: [main.md](https://github.com/Tomasz-Zdeb/Embedded-Systems-Class-Project/blob/master/main.md). Treść powinna zawierać:
  - [x] Przedstawienie charakterystyki komponentów realizujących zadaną funkcjonalność
  - [x] Opis funkcjonalności
  - [x] Schemat logiczny obrazujący podłączenie komponentów (opcjonalnie)
- [x] Dodanie komponentów do schematu elektrycznego projektu (katalog: [schematics](https://github.com/Tomasz-Zdeb/Embedded-Systems-Class-Project/tree/master/schematics))
  - [x] W przypadku braku odpowiedniego modelu stworzenie go
  - [x] Połączenie modelu z układem (mikroprocesor i zasilanie)

Tomasz-Zdeb, 2022-12-28:
Pozwoliłem sobie arbitralnie narzucić następujące I/O:
- wejście cyfrowe dla przycisku UP (podwyższenie progu aktywacji o daną jednostkę np. stopień Celsjusza albo pół stopnia Celsjusza)
- wejście cyfrowe dla przycisku DOWN (obniżenie progu aktywacji o daną jednostkę)
- wejście cyfrowe dla przycisku MODE (zmiana trybu: aktywacja przy zejściu poniżej zadanej temperatury, albo przy wejściu powyżej zadanej temperatury)
- wejście cyfrowe dla przycisku TONE (zmiana wysokości tonu)
- wyjście PWM (sygnał dla buzzera)

Tomasz-Zdeb, 2022-12-28:
Może się przydać z punktu widzenia podłączenia pinu z PWM
https://www.youtube.com/watch?v=x7Djs2mMfuI&ab_channel=PiotrDuba

Tomasz-Zdeb, 2022-12-30:
## FYI
- w Issue: #28 zostały określone piny, używane przez konkretne interfejsy
- w Issue #25 dodano model mikroprocesora do schematu elektrycznego

W związku z czym można dodać komponenty do schematu elektrycznego wraz ze stworzeniem odpowiednich połączeń (co jest do zrobienia w ramach niniejszego zadania)

Closed 2023-01-10.

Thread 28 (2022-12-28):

Określenie przykładowej konfiguracji mikroprocesora

Tomasz-Zdeb, 2022-12-28:
Zgodnie z Issues: #22 #25 wybraliśmy mikroprocesor i dodaliśmy go do schematu. Dalszym krokiem - bardzo istotnym, ponieważ blokuje on Issues: #11 #15 #21 #26 i #27 przed zrealizowaniem połączeń z mikroprocesorem na schemacie elektycznym jest określenie na których pinach mikroprocesora można skonfigurować daną funkcjonalność.

AC:
- Zgodnie z #22 sprawdzono potencjalną konfigurację używanych interfejsów (czyli np. na jakich pinach znajduje się SPI1 mikroprocesora itd...)
- Konfiguracja każdego z interfejsów jest umieszczona w niniejszym Issue w postaci screenshotów przedstawiających jakie piny są używane przez dany interfejs)

#### Przydatne Źródła
- [https://docs.espressif.com/projects/esp-at/en/latest/esp32/Compile_and_Develop/esp32-sdio-at-guide.html](https://docs.espressif.com/projects/esp-at/en/latest/esp32/Compile_and_Develop/esp32-sdio-at-guide.html)
- [https://www.digikey.pl/en/maker/projects/getting-started-with-stm32-how-to-use-spi/09eab3dfe74c4d0391aaaa99b0a8ee17](https://www.digikey.pl/en/maker/projects/getting-started-with-stm32-how-to-use-spi/09eab3dfe74c4d0391aaaa99b0a8ee17)
- [https://www.bluedot.space/tutorials/how-many-devices-can-you-connect-on-i2c-bus/](https://www.bluedot.space/tutorials/how-many-devices-can-you-connect-on-i2c-bus/)

#### Przykład z STM32CubeIDE dla SDIO
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

KamilTworzydlo, 2022-12-30:
![Uploading D220C280-8694-4B93-9C6A-D2C037598093.png…]()

KamilTworzydlo, 2022-12-30:
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

KamilTworzydlo, 2022-12-30:
![Uploading 920447F1-CF58-4527-B8C5-0D5D335B50F2.png…]()

KamilTworzydlo, 2022-12-30:
Wybrany mikroprocesor #22 obsługuje 4bitową obsługę **SDIO**, czyli natywną komunikację z nośnikami w postaci kart **SD** i **micro SD**. Prawdopodobnie tryb 1-bitowy zapewniłby wystarczającą prędkość transmisji do zapisu danych pozyskiwanych przez urządzenie, ale ze względu na jedynie częściowe wykorzystanie potencjału mikroprocesora, można skorzystać z trybu 4-bitowego zapewniającego bezpieczny zapas prędkości transmisji.
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
W przypadku konfiguracji interfejsu **I2C** można pozostawić domyślne ustawienia, ponieważ liczba urządzeń komunikujących się po tej magistrali będzie niewielka (2 komponenty i mikrokontroler), w związku z czym nie ma konieczności ingerencji w takie parametry jak prędkość zegara.
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
Z analizy dokumentacji konwertera napięć termopary (modułu obsługującego termoparę #8):
https://www.mouser.pl/new/maxim-integrated/maximmax31855/
https://www.mouser.pl/pdfDocs/MAX31855.pdf
oraz analizie materiałów:
https://www.youtube.com/watch?v=eFKeNPJq50g&ab_channel=Digi-Key
https://fastbitlab.com/nss-setting-stm32-master-slave-mode/
https://www.digikey.com/en/maker/projects/getting-started-with-stm32-how-to-use-spi/09eab3dfe74c4d0391aaaa99b0a8ee17
konfiguracja interfejsu **SPI** sprowadzała się będzie do ustawienia trybu **Master** (Mikroprocesor-master, konwerter-slave) **half-duplex**.
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
Ze względu na brak jednolitego standardu komunikacji **SPI** istotne są parametry **CPOL** i **CPHA** określające przebieg transmisji względem polaryzaji zegara i linii danych. Według dokumentacji konwertera można pozostać przy ustawieniach domyślnych **STM32CubeIDE**, tj. polaryzacja zegara: sygnał niski (Low) i faza zegara na krawędzi narastającej (1 Edge). Są to najpopularniejsze wartości tych parametrów, jakie spotyka się w komunikacji **SPI**.
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
Najistotniejszym elementem konfiguracji wyjścia **PWM** jest ustawienie źródła sygnału zegara na zegar wewnętrzny i ustawienie generowania sygnału **PWM** na kanale pierwszym. Pozostałe parametry można pozostawić z wartościami domyślnymi.
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
W przypadku wejść cyfrowych, konfiguracja polega na arbitralnym doborze nieużywanych pinów i ustawienia ich trybu pracy na **input mode**.
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

---

Z powyższej analizy konfiguracji uzyskujemy następujący pinout (**SYGNAŁ** -> **PIN**):

- SDIO
  - D0 -> PC8
  - D1 -> PC9
  - D2 -> PC10
  - D3 -> PC11
  - CK -> PC12
  - CMD -> PD2
- I2C
  - SCL -> PB8
  - SDA -> PB9
- SPI
  - MOSI -> PA12
  - NSS -> PA15
  - SCK -> PB3
- PWM
  - CH1 -> PA5
- GPIO
  - PB12
  - PB13
  - PD10
  - PD13
  - PE15

---

(Istotne dla osób podłączających komponenty na schemacie elektrycznym)

W przypadku konieczności zastosowania rezystora pull-up (pull up resistor) istnieje możliwość realizacji takiej funkcjonalności na etapie konfiguracji, nie trzeba wówczas fizycznie podłączać takowego rezystora.

https://en.wikipedia.org/wiki/Pull-up_resistor

Tomasz-Zdeb, 2022-12-30:
Dobra robota 👍🏻 bardzo przystępne opracowanie 😀

Closed 2022-12-30.

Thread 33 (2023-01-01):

Aktualizacja kosztorysu

Tomasz-Zdeb, 2023-01-01:
Aktualizacja kosztorysu stworzonego w ramach zadania: #29

AC:
- [x] kosztorys uwzględnia zaktualizowaną kartę **SD** i gniazdo - Issue #10
- [x] kosztorys uwzględnia trzy chipy interpretujące napięcia ale tylko jedną termoparę (zestaw podstawowy)
- [x] kosztorys uwzględnia trzy chipy interpretujące napięcia i cztery termopary (zestaw rozszerzony)
- [x] kosztorys uwzględnia mostek **I2C** to **SPI**
- [x] kosztorys w obu wariantach zawiera pięć zacisków <https://www.mouser.pl/ProductDetail/Amphenol-Anytek/VI0321550000G?qs=Mv7BduZupUjI2aG91xVokw%3D%3D> (cztery dla termopar i jeden na moduł rozszerzeń)
- [x] cena sumaryczna komponentów w kosztorysie nosi nazwę: `Cena prototypu`
- [x] kosztorys zawiera poniżej pola: `Cena prototypu` i `Cena seryjna` z wyjaśnieniem że przy zakupie komponentów w dużych ilościach cena jest mniejsza (zadecydować o wartości procentowej patrząc na ceny w zależności od ilości u dostawcy **Mouser Electronics**

D4RK0N3dev, 2023-01-07:
3 czipy nie 4

Tomasz-Zdeb, 2023-01-09:
Zaktualizowałem **Acceptance Criteria** o:
- trzy czipy
- trzy moski **I2C** to **SPI**

Closed 2023-01-14.

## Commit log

2022-10-12 KiCad project initialization
    [Embedded-Systems-Class-Project.kicad_pcb, Embedded-Systems-Class-Project.kicad_sch]
2022-11-10 added thermocouple and amplifier to kicad schematic
    [Embedded-Systems-Class-Project.kicad_sch]
2022-11-26 lcd and i2c converter schematic
    [Embedded-Systems-Class-Project.kicad_sch]
2022-11-27 updated schematic with micro sd card model
    [Embedded-Systems-Class-Project.kicad_sch]
2022-12-28 Untrack some KiCad files
2022-12-28 Added Microprocessor to schematic
    [Embedded-Systems-Class-Project.kicad_sch]
2022-12-31 poprawki tact switch
2023-01-03 added connections to schematic
    [Embedded-Systems-Class-Project.kicad_sch]
2023-01-03 added additional thermocouples and converters
    [Embedded-Systems-Class-Project.kicad_sch]
2023-01-05 updated schematic and library
    [Embedded-Systems-Class-Project.kicad_sch]
2023-01-10 Issue 21 - opisanie komunikacji bluetooth
    [Embedded-Systems-Class-Project.kicad_sch]
2023-01-10 feat(#27): Realizacja issue nr. #27
    [Embedded-Systems-Class-Project.kicad_sch]
2023-01-14 Realizacja issue 21 - przechowywanie danyc
    [Embedded-Systems-Class-Project.kicad_sch]
